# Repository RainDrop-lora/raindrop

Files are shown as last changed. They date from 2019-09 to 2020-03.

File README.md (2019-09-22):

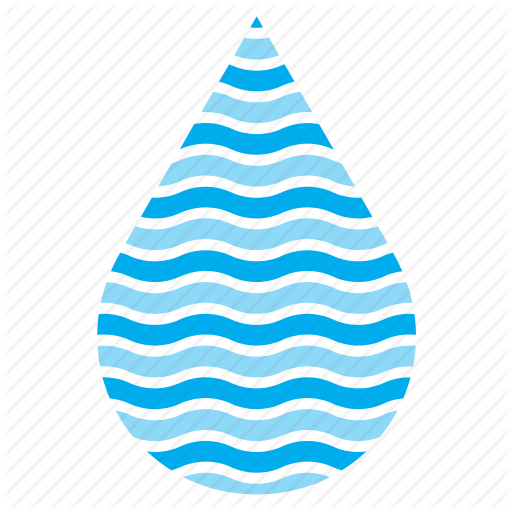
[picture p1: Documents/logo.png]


# RainDrop

Soil moisture monitoring system on LoRaWAN Network

## Problem

Resources watering city greenery are 
used sub-optimally.
It is complicated for the city to 
monitor work of subcontractors responsible
for city plants.
Rapidly changing climate makes watering an important task.

## Solution
System of wireless sensors that
measures soil moisture.

## Gains
* Municipality Gains means to evaluate work of subcontractors
* Community gains means to take care of community-planted trees
* Business gains means to optimally allocate resources 

## Architecture
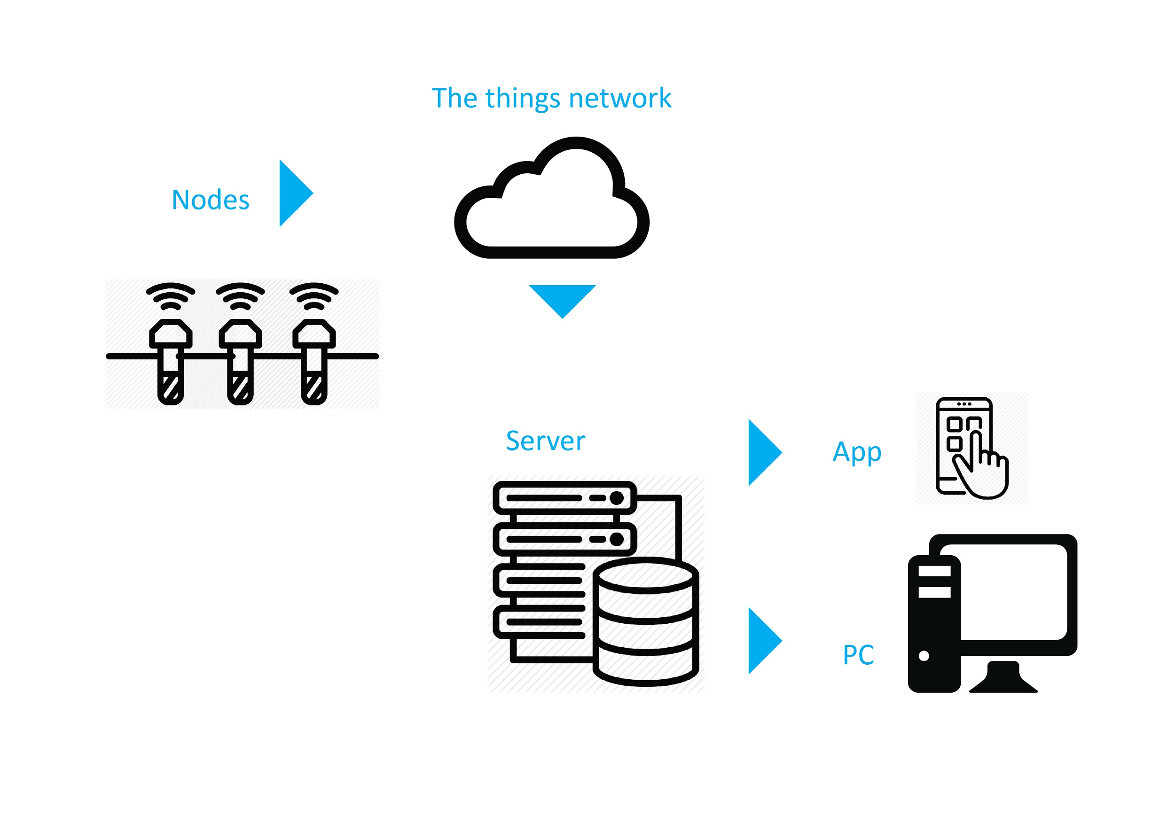
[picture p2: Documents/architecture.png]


## Results
* hardware prototype
* backend prototype
* cost analysis
* enduser application prototype
* all work is released under open source licence

## Plans
* order the first batch of PCBs next week
* work on battery life optimization
* deploy two LoRa gateways in next month

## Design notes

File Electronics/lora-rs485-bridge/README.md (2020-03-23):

# LoRa - RS485 bridge

This is a board that is specifically designed to easily hook up RS485 and I2C sensors to LoRaWAN network.
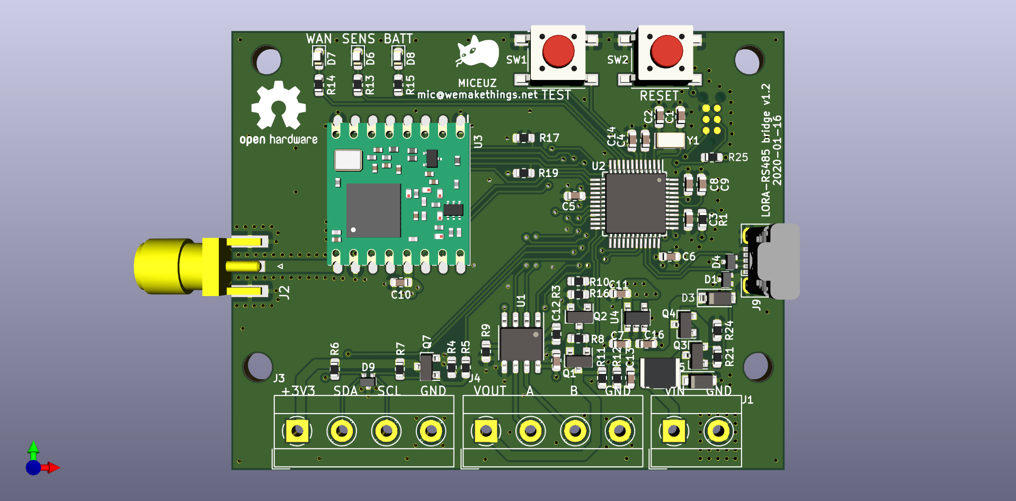
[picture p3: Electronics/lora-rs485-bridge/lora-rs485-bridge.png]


## Features

* Arduino compatible (Adafruit Feather M0 based)
* Low power:
  * Sleep current - 15uA
  * Message cost @ SF7 - 38mC (~190k messages from 4xAA battery)
  * Power switching for external I2C and RS485 sensors
* ESD protection
* Reverse polarity protection
* Wide input voltage range (up to 12V)
* Footprint for edge SMA antenna connector 

## Hardware resources

 * Connector J1 is power input, 12V max
 * Connector J4 is RS485 interface. VOUT on this connector is connected directly to the positive power input. Current of up to 500mA can be supplied from this connector. Q2 and Q1 form a high side switch to switch power to the connected RS485 bus. Digital pin **2** in Arduino environment can be used to switch power on and off.
 * Connector J3 is I2C interface. +3V3 on this connector is connected to the onboard +3V3 regulator. Up to 100mA can be supplied from this connector. R6 and R7 are I2C pullup resistors with the value of 4.7Ohm. Q7 is a switch that controls power to this connector. Digital pin **5** in Arduino environment can be used to controll this switch. Control logic is inverted, i.e. writing pin 5 HIGH will disconnect power to J3 and pullups, writing pin 5 LOW, will connect +3V3 to J3 and pullups.
 * SWD connector is provided for debugging and low level programming. 6-pin [Tag-Connect](https://www.tag-connect.com/product-category/products/cables/6-pin-target) connector can be used
 * Battery level is measured thru resistors R11, R12. Battery voltage is provided to this resistive divider when power to RS485 port is enabled. Voltage proportional to battery voltage is provided on analog pin **A0**. If using power supplies higher than 9V adjust values of resistors R11, R12 accordingly.
 * Led WAN is connected to digital pin **18**
 * Led SENS is connected to digital pin **17**
 * Led BATT is connected to digital pin **16**
 * Button TEST is connected to pin **A1**
 * Button RESET is connected to RESET line of the microcontroller U2.

## Power

The board is designed to be used with 4xAA 1.5V cells, actually physical dimensions of the board resemble a common cheap 4xAA holder. This strategy was chosen because for low power device it makes little sense to use recheargable batteries as you probably will not want to bring back device from field to charge it, it's much more practical to just change the batteries. 4xAA configuration allows to use up full capacity of AA cell - typically AA cells are totally flat at 0.8V, thus the circuit will stay fully operational till the batteries are flat - 0.8x4=3.2V while microcontroller works down to 2.5V and RFM69 module works down to 1.8V. 

Nevertheless, power sources up to 12V can be used. Also rechargeable LiPo cells can be used. 

## Antenna

A SMA connector is available on board, a right angle SMA connector designed for 1.6mm thickness board can be fitted. 

Nevertheless, a simple wire works just fine, I was able to transmit messages up to 10km away using a simple piece of wire as an antenna. Solder a piece of single core wire and cut it to a length for your frequency:
 * 868Mhz - 86.3mm
 * 915MHz - 81.9mm

## Firmware

A working example firmware source code is provided. The firmware takes care of setting up radio module, sleep, querying sensors and formatting payload and transmission. 

### Programming environment setup

A tutorial provided by [Adafruit for Feather M0 boards](https://learn.adafruit.com/adafruit-feather-m0-basic-proto/setup) can be followed for the programming environment setup. In a nutshell:

 * Use Arduino IDE version 1.8 or higher
 * Add this line to **Additional Boards Manager URLs** in preferences dialog: `https://adafruit.github.io/arduino-board-index/package_adafruit_index.json`
 * In the **Boards Manager** add support for **Arduino SAMD Boards** version 1.6.11 or later
 * In the **Boards Manager** add support for **Adafruit SAMD Boards**
 * In **Tools->Board** menu choose **Feather M0**; that's it, you are ready to go

### Libraries used

 * [arduino-lmic](https://github.com/mcci-catena/arduino-lmic) -- you can add it via Arduino Library manager, but cloning the git repo is strongly recommended to get all the latest fixes
 * [RTCZero](https://github.com/arduino-libraries/RTCZero) -- can be installed from Arduino Library manager

## Indication and UI

Three leds are provided on the board called WAN, SENS and BATT. It is up to the user to decide how exaclty to use them, but general guidance is that WAN led displays radio activity, SENS led provides sensor activity or status indication and BATT led provides battery status indication.

RESET and TEST buttons are available. RESET button resets the microcontroller, also it can be used to enter the bootloader mode for firmware upload. If sleep is utilised in the firmware, doubleclick the RESET button to enter the bootloader.

TEST button usage is up to the user.

Serial port is availale via USB-CDC interface, it can be used for debug messages, command line interface or other uses to be decided by the user. Note that in sleep mode USB is disconnected, disable sleep in the firmware to use the serial port.

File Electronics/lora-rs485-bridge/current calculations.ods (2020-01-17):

 | Typical, uA | Max, uA
TVS | 1 | 5
MCU | 4 | 12
Regulator | 4 | 8
RS485 | 4.1 | 6
Radio | 0.2 | 1
 | 13.3 | 32
 |  | uA
Reg+MCU in deep sleep |  | 7.8
Reg+MCU+Radio |  | 59

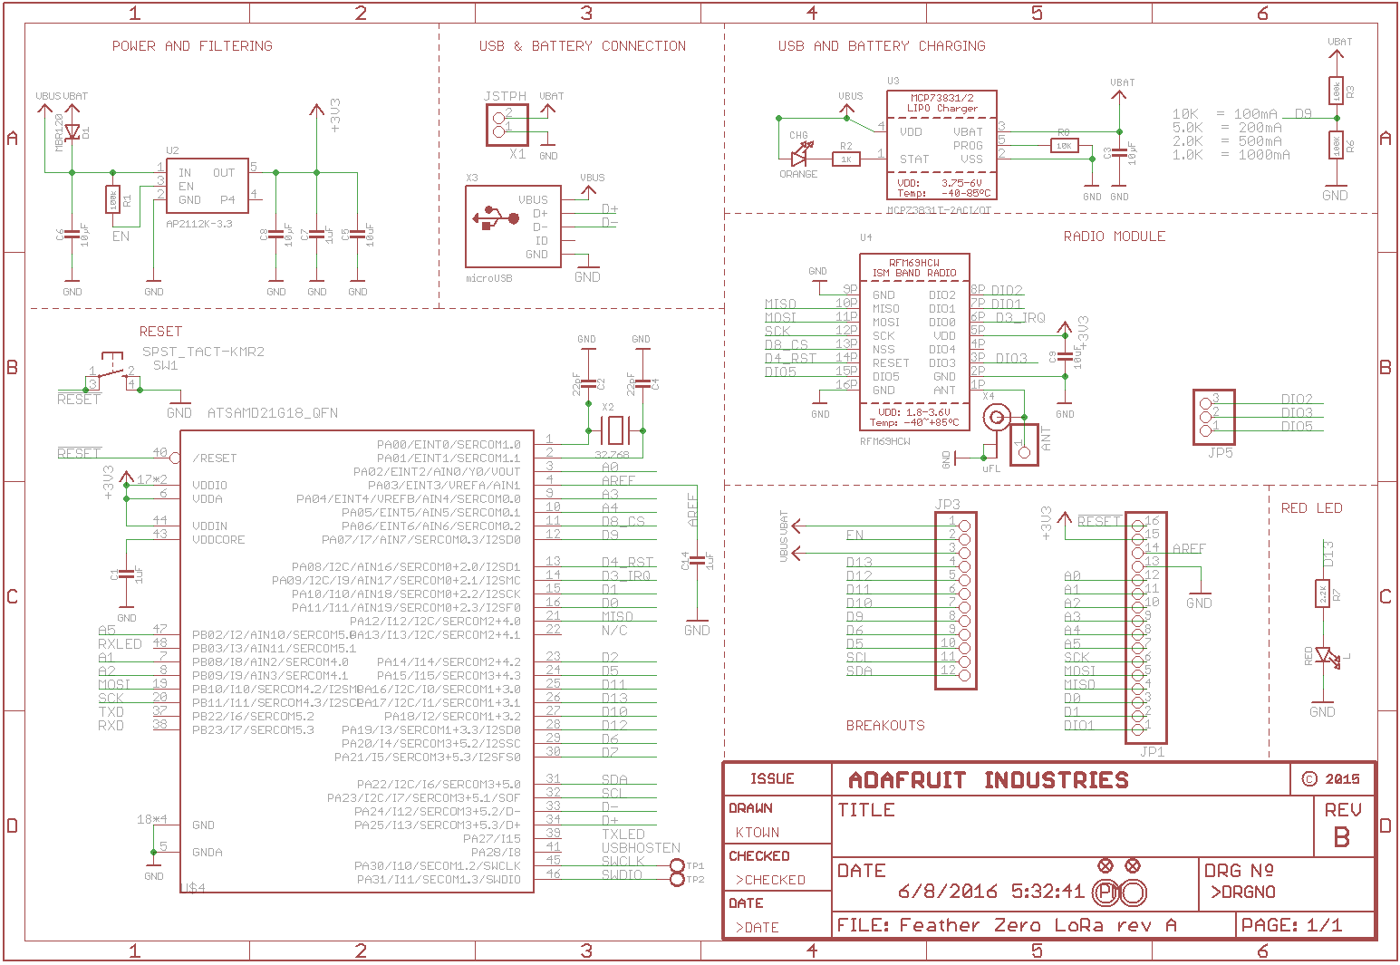
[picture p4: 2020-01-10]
Electronics/lora-rs485-bridge/feather_schem.png

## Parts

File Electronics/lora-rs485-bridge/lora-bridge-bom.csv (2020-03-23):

Item | Qty | Reference(s) | Value | Footprint | DNP | PartNo | Manufacturer | Comment
1 | 2 | C1, C2 | 22p | Capacitor_SMD:C_0603_1608Metric
2 | 9 | C3, C4, C5, C6, C8, C9, C12, C13, C14 | 1u | Capacitor_SMD:C_0603_1608Metric |  |  |  | Generic X5R capacitor
3 | 4 | C7, C10, C11, C16 | 4.7u | Capacitor_SMD:C_0603_1608Metric |  | C1608X5R1C475K080AE | TDK
4 | 3 | D1, D4, D9 | D_TVS_x2_AAC | miceuz-lib:SC89 |  | NZL5V6AXV3T1G | ON SEMICONDUCTOR
5 | 1 | D2 | 7.6V | Diode_SMD:D_SOD-323 |  | MM3Z7V5ST1G | ON SEMI
6 | 1 | D3 | 1N4148 | Diode_SMD:D_SOD-123 |  | 1N4148W-7-F | Diodes Inc
7 | 1 | D5 | D_TVS | Diode_SMD:D_SOD-123F |  | SMF11A | Littlefuse
8 | 3 | D6, D7, D8 | LED | LED_SMD:LED_0603_1608Metric
9 | 1 | J1 | battery | TerminalBlock_MetzConnect:TerminalBlock_MetzConnect_Type101_RT01602HBWC_Pitch5.08mm
10 | 1 | J2 | ANT | miceuz-lib:SMA_6.35_EdgeMount |  | CON-SMA-EDGE-S | RF Solutions | Can be replaced with compatible footprint connector specified up to 3GHz, VSWR < 1.2
11 | 1 | J3 | i2c | TerminalBlock_MetzConnect:TerminalBlock_MetzConnect_Type101_RT01604HBWC_Pitch5.08mm
12 | 1 | J4 | rs485 | TerminalBlock_MetzConnect:TerminalBlock_MetzConnect_Type101_RT01604HBWC_Pitch5.08mm
13 | 1 | J5 | SWD | miceuz-lib:TC2030-MCP-NL | DNP
14 | 1 | J9 | USB micro | Connectors_USB:USB_Micro-B_Vertical_Molex-105133-0001 |  | 1051330011 | MOLEX
15 | 4 | Q1, Q3, Q4, Q7 | Q_PMOS_GSD | Package_TO_SOT_SMD:SOT-23 |  | NX2301P,215 | NXP | Exact as specified
16 | 1 | Q2 | Q_NMOS_GSD | Package_TO_SOT_SMD:SOT-23 |  | NTR4003NT1G | ON SEMICONDUCTOR
17 | 5 | R1, R13, R14, R15, R25 | 1k | Resistor_SMD:R_0603_1608Metric
18 | 9 | R3, R4, R8, R9, R16, R17, R19, R21, R24 | 1M | Resistor_SMD:R_0603_1608Metric |  |  |  | Generic 5% resistor
19 | 2 | R5, R10 | 150 | Resistor_SMD:R_0603_1608Metric
20 | 2 | R6, R7 | 4.7k | Resistor_SMD:R_0603_1608Metric
21 | 1 | R11 | 20k | Resistor_SMD:R_0603_1608Metric
22 | 1 | R12 | 10k | Resistor_SMD:R_0603_1608Metric
23 | 1 | SW1 | SW_Test | Button_Switch_SMD:SW_Push_1P1T_NO_6x6mm_H9.5mm
24 | 1 | SW2 | SW_Reset | Button_Switch_SMD:SW_Push_1P1T_NO_6x6mm_H9.5mm
25 | 1 | TH1 | Thermistor_PTC | Fuse:Fuse_1206_3216Metric |  | nSMD075-13.2V | TECHFUSE
26 | 1 | U1 | SN65HVD72 | Package_SO:SOIC-8_3.9x4.9mm_P1.27mm |  | SN65HVD72DR | TEXAS INSTRUMENTS
27 | 1 | U2 | ATSAMD21G18A-AUT | Package_QFP:TQFP-48_7x7mm_P0.5mm |  | ATSAMD21G18A-AUT | Microchip
28 | 1 | U3 | RFM95W-868S2 | miceuz-lib:RFM95 |  | RFM95W-868S2 | HopeRF
29 | 1 | U4 | NCP718 | TO_SOT_Packages_SMD:SOT-23-5 |  | NCP718ASN330T1G | ON SEMICONDUCTOR
30 | 1 | Y1 | 32.768 | Crystals:Crystal_SMD_3215-2pin_3.2x1.5mm |  | FC-135 32.7680KA-A5 | EPSON

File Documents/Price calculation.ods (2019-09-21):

Name | Price, Eur
Electronic parts | 15 | 15 | 15 | 38.4
Electronic assembly | 3.5 | 3.5 | 3.5
Antenna | 1.8 | 1.8 | 1.8
Battery holder | 0.6 | 0.6 | 0.6
Case | 8.45 | 8.45 | 8.45
Cable gland | 0.2 | 0.2 | 0.2
Fixing parts | 5
Welding | 5
Belt | 5.2
Screws, etc | 1 | 1 | 1
Assembly | 2 | 2 | 2
Sensor | 16.34 | 16 | 0
Total | 64.09 | 48.55 | 32.55
+60% markup | 38.454 | 29.13 | 19.53
Sale price | 102.544 | 77.68 | 52.08
 |  |  | 83.328

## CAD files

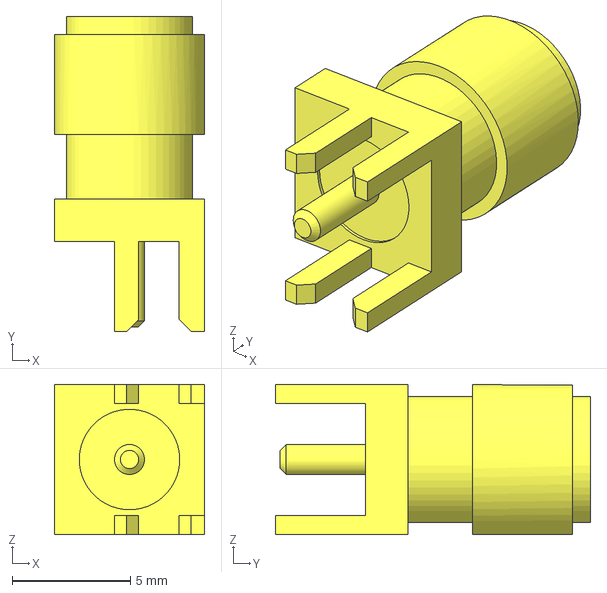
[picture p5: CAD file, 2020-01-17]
Electronics/lora-rs485-bridge/SMA-J-P-H-ST-EM1.STP--3DModel-STEP-66336.STEP
6.35 x 13.3 x 6.35 mm

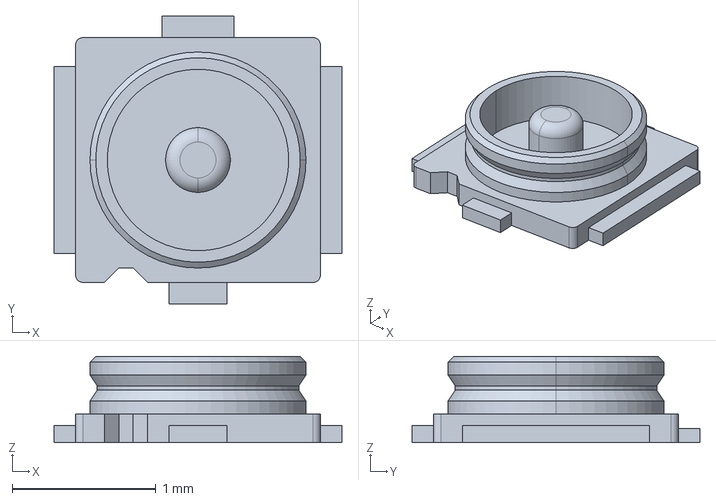
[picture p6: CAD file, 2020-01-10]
Electronics/lora-rs485-bridge/c-2334884-1-a2-3d.stp
2.00 x 2.00 x 0.6 mm

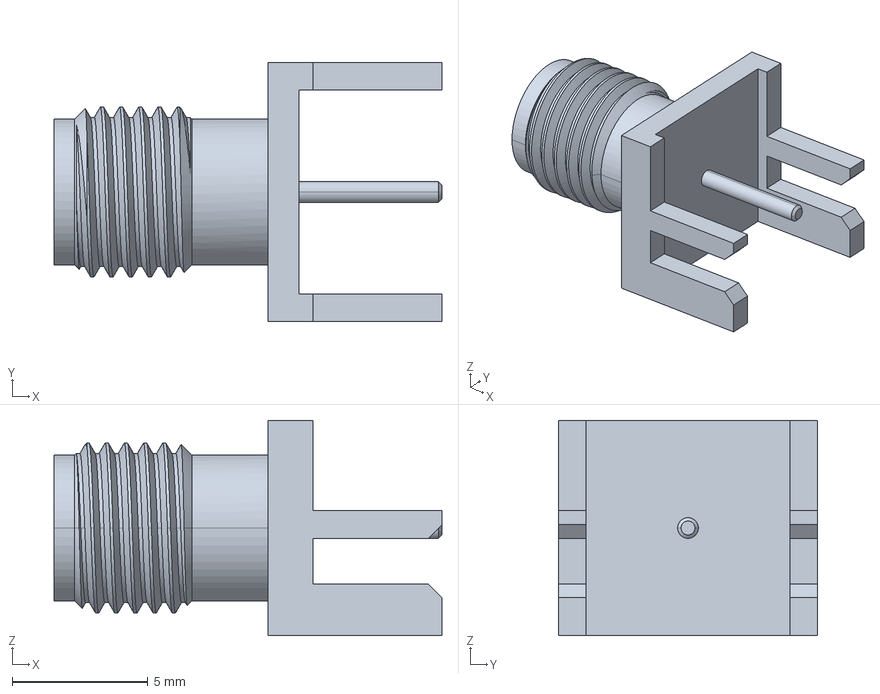
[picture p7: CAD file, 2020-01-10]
Electronics/lora-rs485-bridge/732511150.stp
14.3 x 9.53 x 7.92 mm

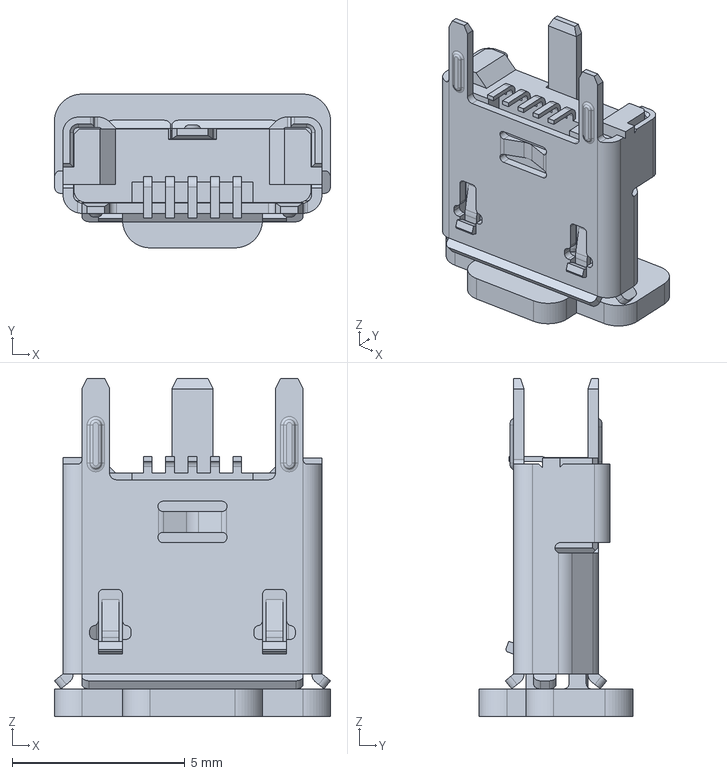
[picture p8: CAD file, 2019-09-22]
Electronics/lora-rs485-bridge/1051330011.stp
8.00 x 4.45 x 9.78 mm

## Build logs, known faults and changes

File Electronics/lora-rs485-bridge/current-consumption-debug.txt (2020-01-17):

# V1.0 board is analysed

Both MCU and RFM95 are in sleep.

VCC - 6V

Overall current consumption stays at 305uA

* RFM95 VCC pin draws 0.5uA 
* RFM95 GND current is 0.5uA

RFM95 removed from board, RS485 transceiver removed
Board cleaned

pin level is set to default sleep value before setting it as input -- this seems to have impact

Overall current consumption is 9uA

RS485 transceiver put back

Overall current consumption is 12uA

Code changed to enable RS485 transceiver at the startup

RFM95 soldered back with resistors:
 * DIO01 - 10k
 * IRQ - 10k
 * MISO - 10k
 * MOSI - 330
 * SCK - 330
 * NSS - 330
 * RST - 10k

RFM95 is not initialized in FW

Overall current consumption is 2mA

RFM95 initialization put back to FW

Overall current consumption is 10mA, MCU does not finish initializing RFM95

MISO resistor replaced to 220

Initialization passes. Current consumption is about 38uA
Touching MISO line at RFM95 size reduces current consumption down to 12uA
Rising the board from antistatic pad also reduces current consumption down to 10-12uA. 
Holding hand over board increases current consumption.

MISO resistor replaced with a link

Overall current consumption is 10uA
Board is on longer susceptable to hand movement or placement on antistatic pad

RST resistor replaced with a link

NO change - Overall current consumption is 10uA

DIO01 resistor replaced with a link

NO change - Overall current consumption is 10uA

IRQ resistor replaced with a link

NO change - Overall current consumption is 10uA

MOSI resistor replaced with a link

NO change - Overall current consumption is 10uA

SCK resistor replaced with a link

NO change - Overall current consumption is 10uA

NSS resistor replaced with a link

NO change - Overall current consumption is 10uA

* Conclusions: V1.0 board stays in 10uA sleep current with RFM95 connected with no resistors

# V1.1 board is analysed

VCC = 6V
all RFM95 pins are connected via 1k resistor

Overall sleep current is 60uA

Board cleaned with Isopropyl alcohol

Overall sleep current increased to over 100uA, a lot of 50Hz noise visible on current signal

Board cleaned with Isopropyl alcohol even more, MISO resistor replaced with 0 Ohm link

Overall sleep current dropped to 65uA

MOSI and SCK resistors replaced with 0 Ohm - no improvement

RFM95 removed - on improvement, current stays at ~74uA

R24 desoldered - current dropped to 9uA; D3 is a leaky Schottky!!!

D3 replaced with 1n4148 - current is 15uA which is nominal.

RFM95 soldered back

Overall sleep current is 15uA!!!

ALL resistors removed from RFM95 lines, sleep current is still 15uA

#FW changes

pins left as outputs with default sleep high/low states

Overall sleep current is 15uA

Add a 1M pulldown to MISO line - a slight improvement in current consumption - down to 14.5uA, no sensitivity to touching anymore.

# Active mode current consumption

* SF7 -  38mC per message
* SF8 -  43mC
* SF9 -  58mC
* SF10 - 68mC
* SF11 - 119mC
* SF12 - 182mC

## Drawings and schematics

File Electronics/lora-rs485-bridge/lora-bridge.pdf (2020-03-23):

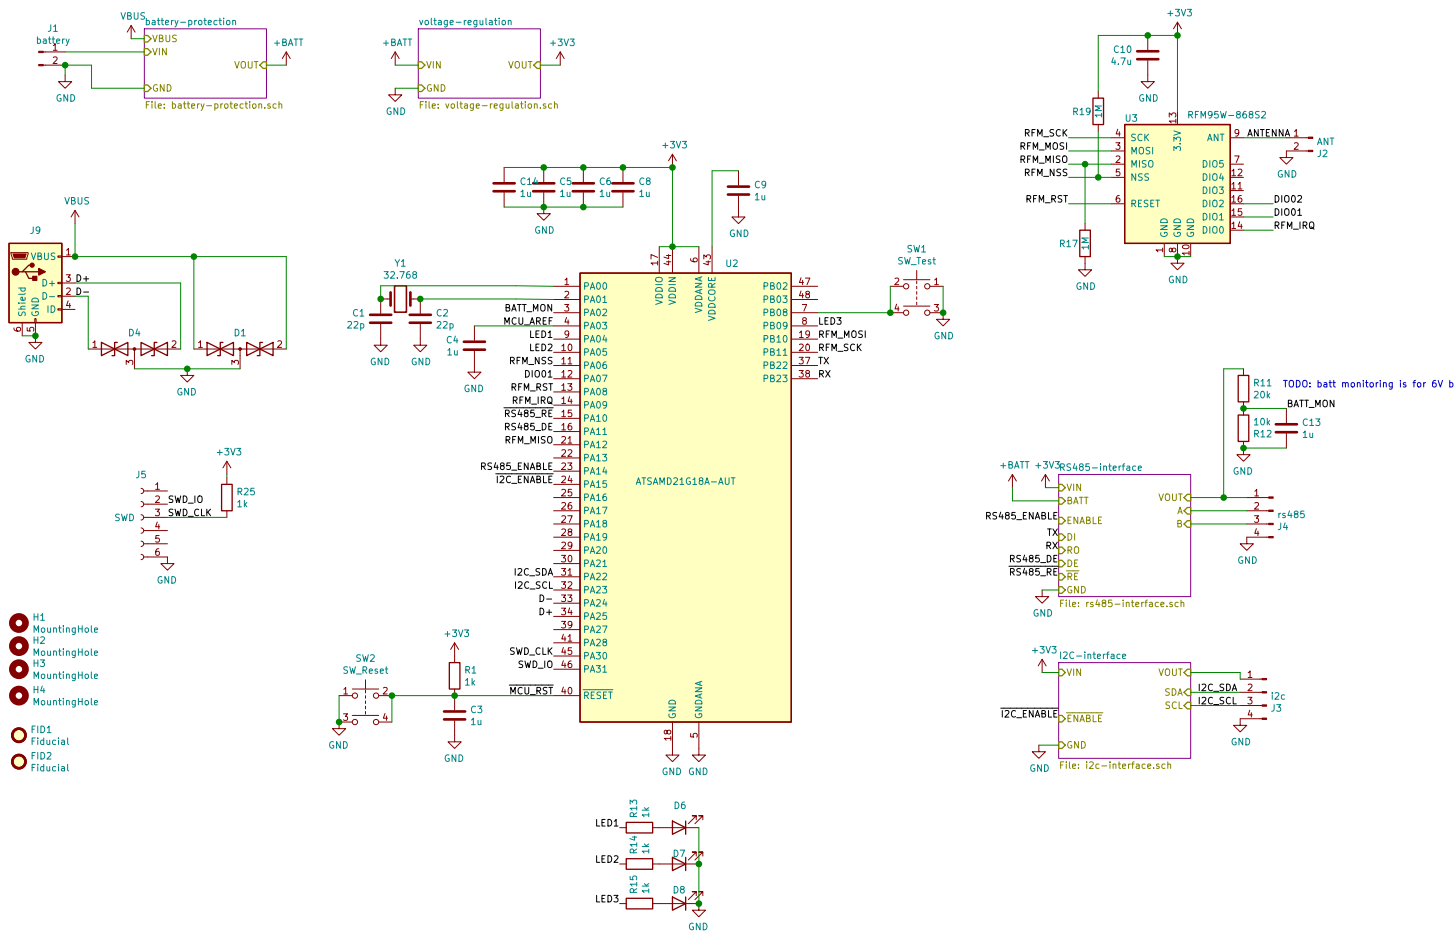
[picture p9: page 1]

battery-protection
VOUT VBUS GND
File: battery-protection.sch VIN

File: voltage-regulation.sch VIN GND

1 GND 10 DIO3 11 DIO4 12 3.3V 13 DIO0 14 DIO1 15 DIO2 16 MISO 2 MOSI 3 SCK 4 NSS 5 RESET 6 DIO5 7 GND

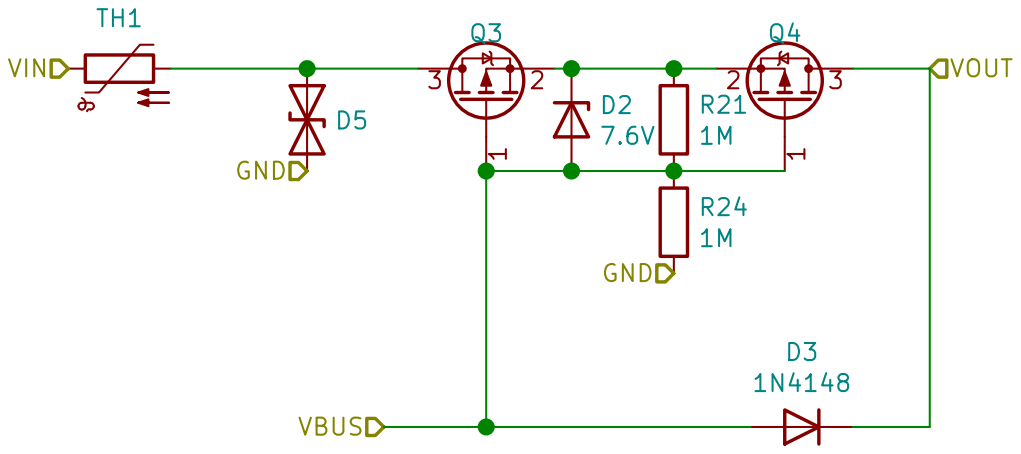
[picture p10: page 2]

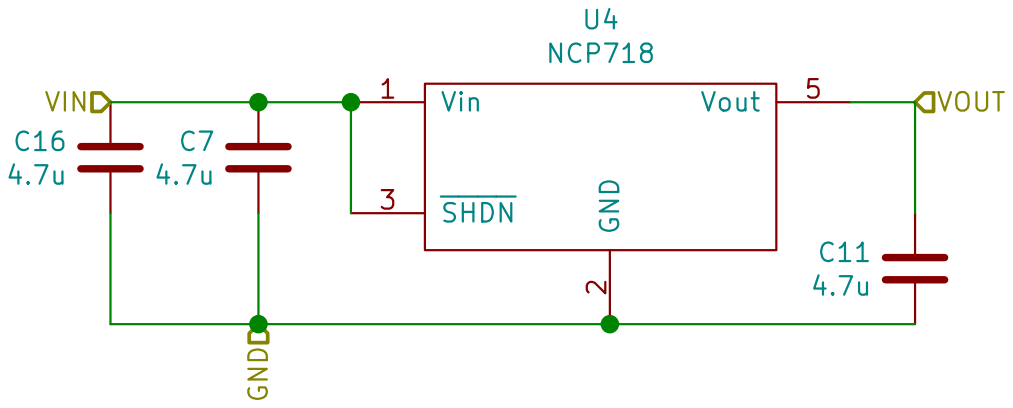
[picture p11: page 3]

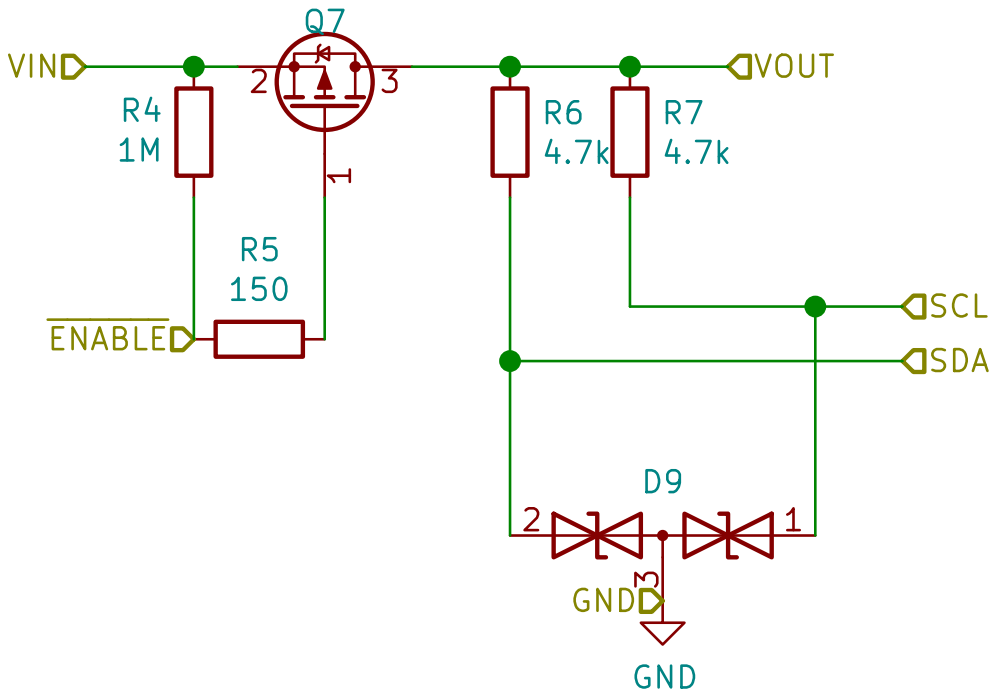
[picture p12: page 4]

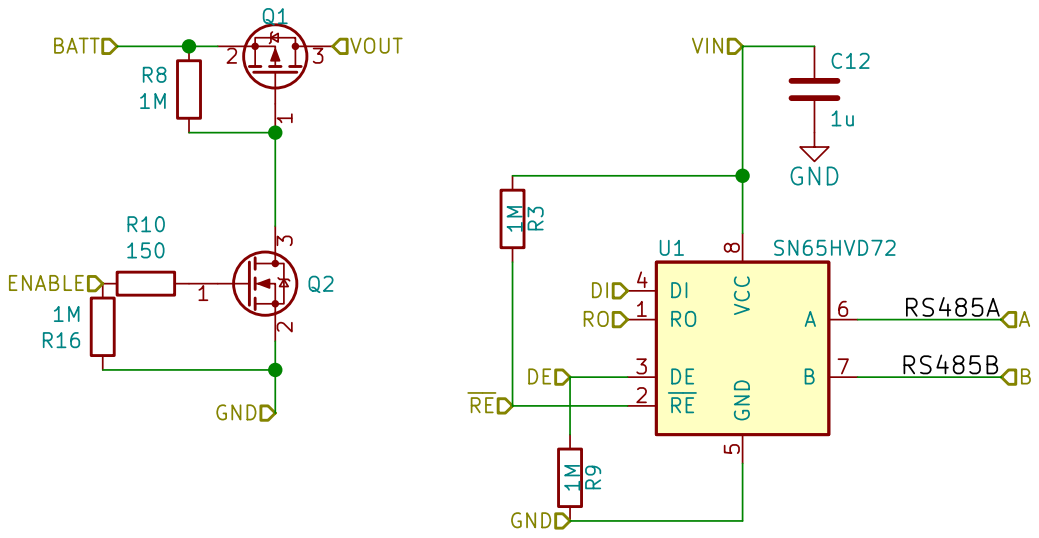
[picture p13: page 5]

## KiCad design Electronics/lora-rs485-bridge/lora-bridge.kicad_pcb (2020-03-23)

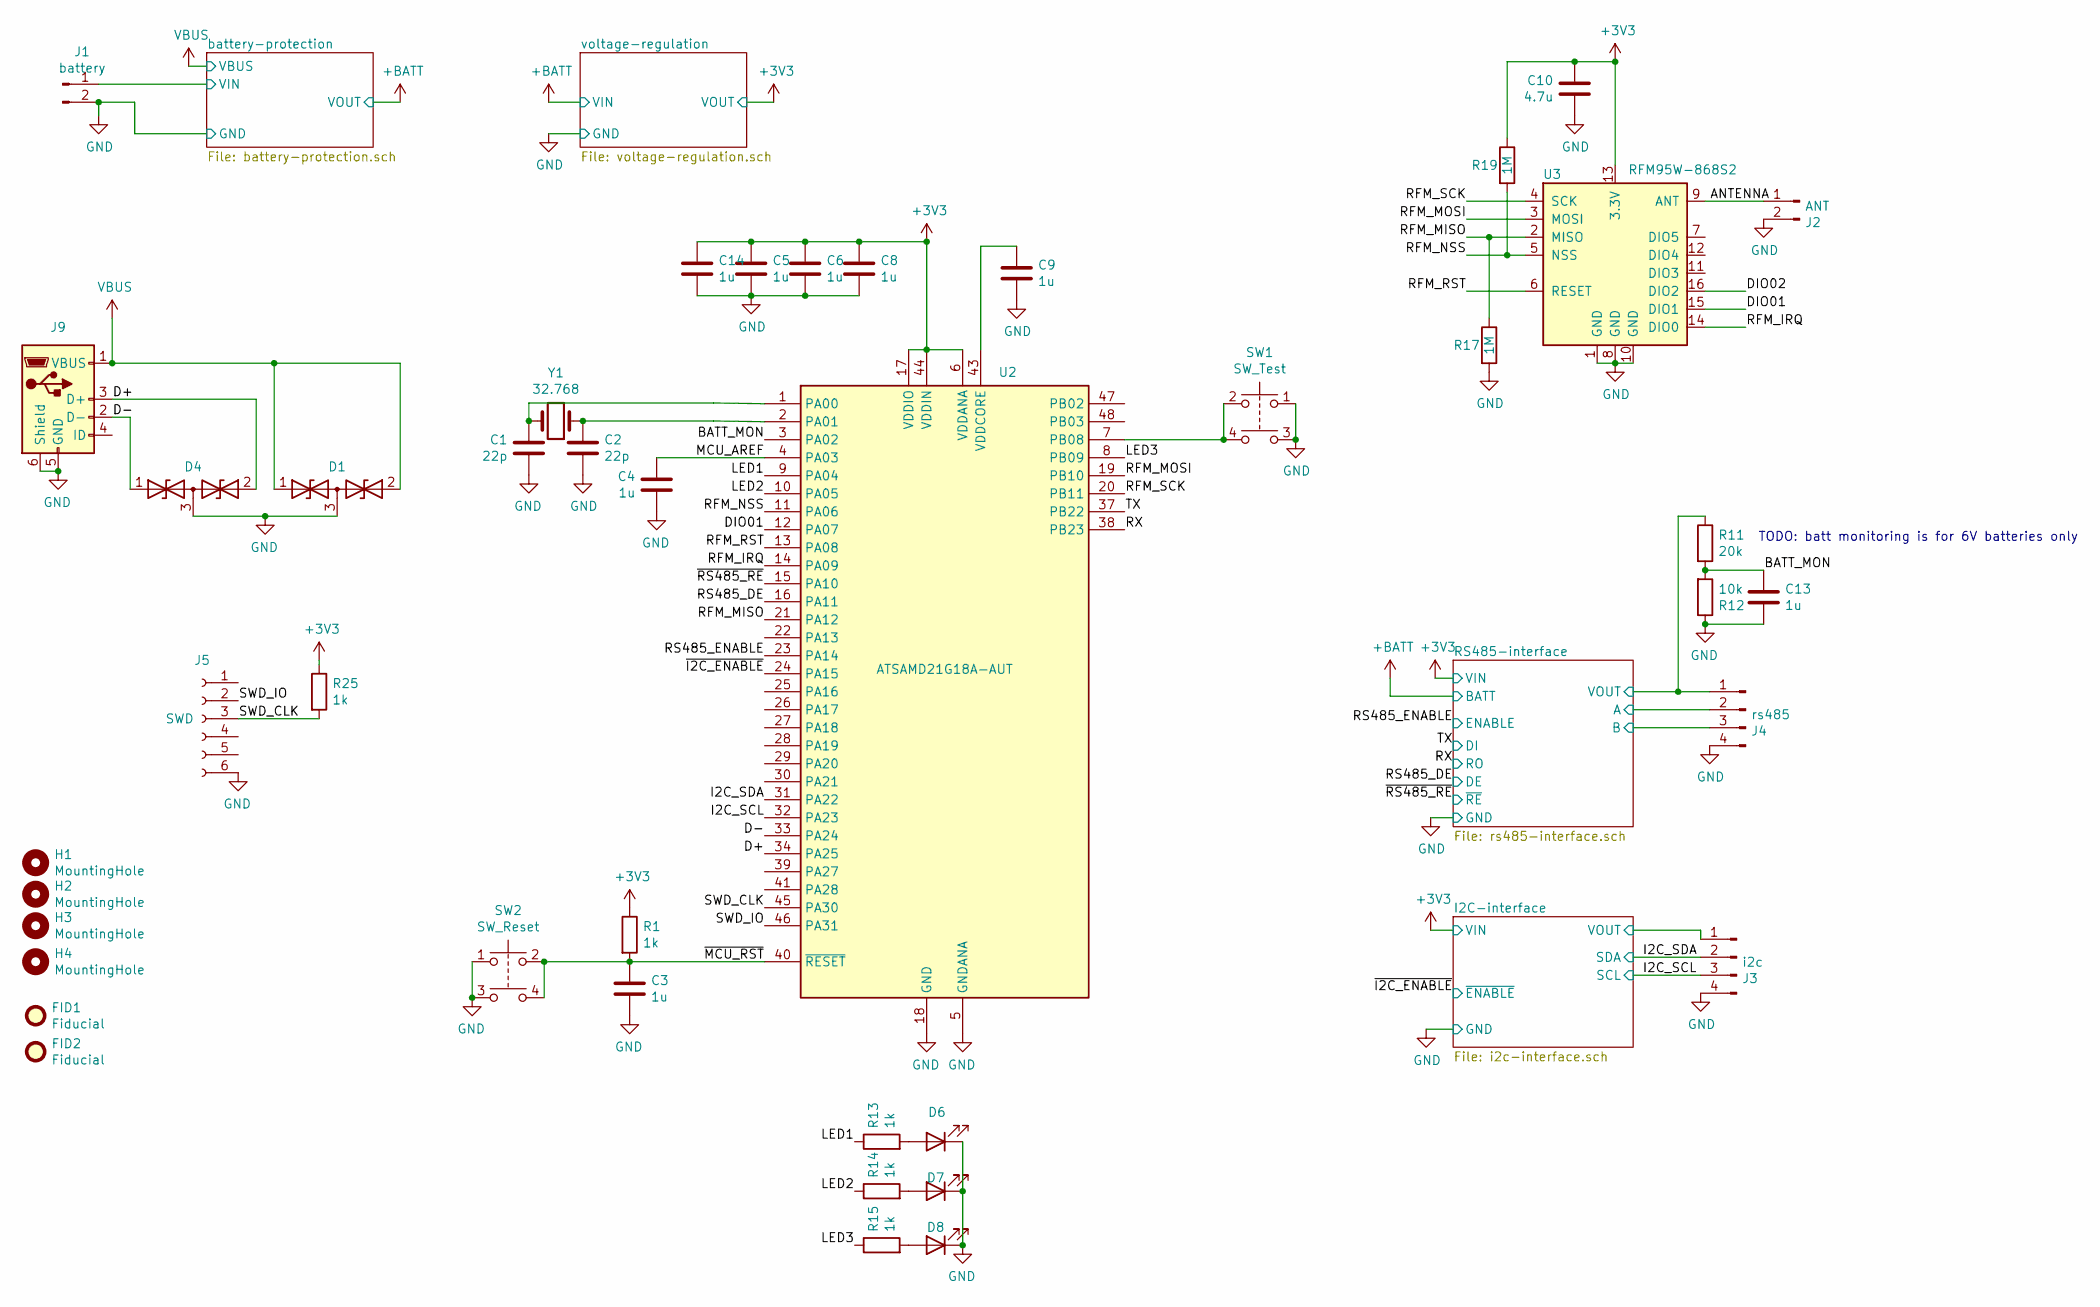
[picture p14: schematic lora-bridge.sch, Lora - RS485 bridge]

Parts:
C1, C2: 22p; C_0603_1608Metric
C3, C4, C5, C6, C8, C9, C13, C14: 1u; C_0603_1608Metric
C10: 4.7u; C_0603_1608Metric; PartNo C1608X5R1C475K080AE
D1, D4: D_TVS_x2_AAC; SC89; PartNo NZL5V6AXV3T1G
D6, D7, D8: LED; LED_0603_1608Metric
FID1, FID2: Fiducial; Fiducial_1mm_Dia_2mm_Outer
H1, H2, H3, H4: MountingHole; MountingHole_3.2mm_M3_DIN965
J1: battery; TerminalBlock_MetzConnect_Type101_RT01602HBWC_Pitch5.08mm
J2: ANT; SMA_6.35_EdgeMount; PartNo CON-SMA-EDGE-S
J3: i2c; TerminalBlock_MetzConnect_Type101_RT01604HBWC_Pitch5.08mm
J4: rs485; TerminalBlock_MetzConnect_Type101_RT01604HBWC_Pitch5.08mm
J5: SWD; TC2030-MCP-NL
J9: USB micro; USB_Micro-B_Vertical_Molex-105133-0001; PartNo 1051330011
R1, R13, R14, R15, R25: 1k; R_0603_1608Metric
R11: 20k; R_0603_1608Metric
R12: 10k; R_0603_1608Metric
R17, R19: 1M; R_0603_1608Metric
SW1: SW_Test; SW_Push_1P1T_NO_6x6mm_H9.5mm
SW2: SW_Reset; SW_Push_1P1T_NO_6x6mm_H9.5mm
U2: ATSAMD21G18A-AUT; TQFP-48_7x7mm_P0.5mm; PartNo ATSAMD21G18A-AUT
U3: RFM95W-868S2; RFM95; PartNo RFM95W-868S2
Y1: 32.768; Crystal_SMD_3215-2pin_3.2x1.5mm; PartNo FC-135 32.7680KA-A5

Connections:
+3V3: C5.1, C6.1, C8.1, C10.1, C14.1, R1.1, R19.1, R25.1, U2.6 (VDDANA), U2.17 (VDDIO), U2.36 (VDDIO), U2.44 (VDDIN), U3.13 (3.3V); also elsewhere on the board
/A: J4.2; also elsewhere on the board
/ANTENNA: J2.1, U3.9 (ANT)
/B: J4.3; also elsewhere on the board
/BATT_MON: C13.1, R11.2, R12.2, U2.3 (PA02)
/D+: D4.2 (A2), J9.3 (D+), U2.34 (PA25)
/D-: D4.1 (A1), J9.2 (D-), U2.33 (PA24)
/DIO01: U2.12 (PA07), U3.15 (DIO1)
/DIO02: U3.16 (DIO2)
/I2C_SCL: J3.3, U2.32 (PA23); also elsewhere on the board
/I2C_SDA: J3.2, U2.31 (PA22); also elsewhere on the board
/LED1: R13.1, U2.9 (PA04)
/LED2: R14.1, U2.10 (PA05)
/LED3: R15.1, U2.8 (PB09)
/MCU_AREF: C4.1, U2.4 (PA03)
/RFM_IRQ: U2.14 (PA09), U3.14 (DIO0)
/RFM_MISO: R17.1, U2.21 (PA12), U3.2 (MISO)
/RFM_MOSI: U2.19 (PB10), U3.3 (MOSI)
/RFM_NSS: R19.2, U2.11 (PA06), U3.5 (NSS)
/RFM_RST: U2.13 (PA08), U3.6 (RESET)
/RFM_SCK: U2.20 (PB11), U3.4 (SCK)
/RS485_DE: U2.16 (PA11); also elsewhere on the board
/RS485_ENABLE: U2.23 (PA14); also elsewhere on the board
/RX: U2.38 (PB23); also elsewhere on the board
/SWD_CLK: J5.3, R25.2, U2.45 (PA30)
/SWD_IO: J5.2, U2.46 (PA31)
/TX: U2.37 (PB22); also elsewhere on the board
/VIN: J1.1; also elsewhere on the board
/VOUT: J4.1, R11.1; also elsewhere on the board
/VOUT_1: J3.1; also elsewhere on the board
/~I2C_ENABLE: U2.24 (PA15); also elsewhere on the board
/~MCU_RST: C3.1, R1.2, SW2.2, SW2.4, U2.40 (~RESET)
/~RS485_RE: U2.15 (PA10); also elsewhere on the board
GND: C1.2, C2.2, C3.2, C4.2, C5.2, C6.2, C8.2, C9.2, C10.2, C13.2, C14.2, D1.3 (common), D4.3 (common), D6.1 (K), D7.1 (K), D8.1 (K), J1.2, J2.2, J3.4, J4.4, J5.6, J9.5 (GND), J9.6 (Shield), R12.1, R17.2, SW1.1, SW1.3, SW2.1, SW2.3, U2.5 (GNDANA), U2.18 (GND), U2.35 (GND), U2.42 (GND), U3.1 (GND), U3.8 (GND), U3.10 (GND); also elsewhere on the board
unnamed: C1.1, U2.1 (PA00), Y1.2
unnamed: C2.1, U2.2 (PA01), Y1.1
unnamed: C9.1, U2.43 (VDDCORE)
unnamed: D6.2 (A), R13.2
unnamed: D7.2 (A), R14.2
unnamed: D8.2 (A), R15.2
unnamed: SW1.2, SW1.4, U2.7 (PB08)
VBUS: D1.1 (A1), D1.2 (A2), J9.1 (VBUS); also elsewhere on the board

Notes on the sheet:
TODO: batt monitoring is for 6V batteries only

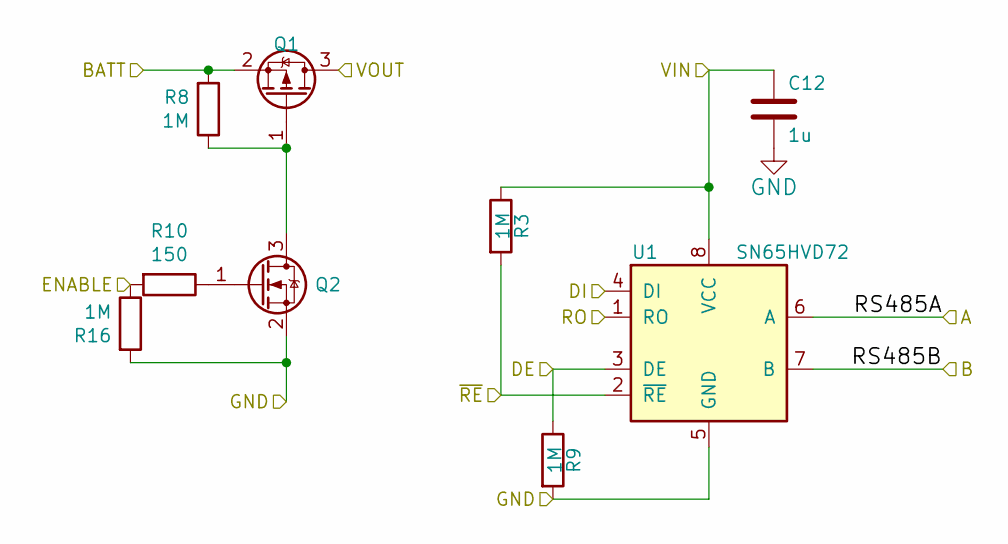
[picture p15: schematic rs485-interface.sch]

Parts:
C12: 1u; C_0603_1608Metric
Q1: Q_PMOS_GSD; SOT-23; PartNo NX2301P,215
Q2: Q_NMOS_GSD; SOT-23; PartNo NTR4003NT1G
R3, R8, R9, R16: 1M; R_0603_1608Metric
R10: 150; R_0603_1608Metric
U1: SN65HVD72; SOIC-8_3.9x4.9mm_P1.27mm; PartNo SN65HVD72DR

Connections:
+3V3: C12.1, R3.1, U1.8 (VCC); also elsewhere on the board
+BATT: Q1.2 (S), R8.2; also elsewhere on the board
/A: U1.6 (A); also elsewhere on the board
/B: U1.7 (B); also elsewhere on the board
/RS485_DE: R9.1, U1.3 (DE); also elsewhere on the board
/RS485_ENABLE: R10.2, R16.1; also elsewhere on the board
/RX: U1.1 (RO); also elsewhere on the board
/TX: U1.4 (DI); also elsewhere on the board
/VOUT: Q1.3 (D); also elsewhere on the board
/~RS485_RE: R3.2, U1.2 (~RE~); also elsewhere on the board
GND: C12.2, Q2.2 (S), R9.2, R16.2, U1.5 (GND); also elsewhere on the board
unnamed: Q1.1 (G), Q2.3 (D), R8.1
unnamed: Q2.1 (G), R10.1

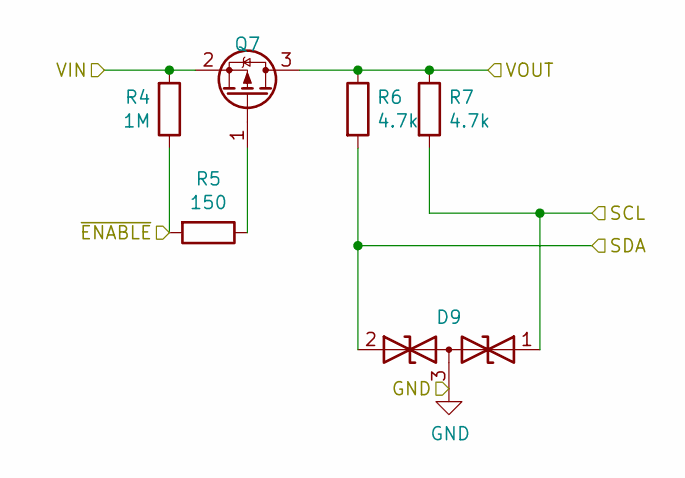
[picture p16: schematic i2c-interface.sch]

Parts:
D9: D_TVS_x2_AAC; SC89; PartNo NZL5V6AXV3T1G
Q7: Q_PMOS_GSD; SOT-23; PartNo NX2301P,215
R4: 1M; R_0603_1608Metric
R5: 150; R_0603_1608Metric
R6, R7: 4.7k; R_0603_1608Metric

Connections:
+3V3: Q7.2 (S), R4.2; also elsewhere on the board
/I2C_SCL: D9.1 (A1), R7.2; also elsewhere on the board
/I2C_SDA: D9.2 (A2), R6.2; also elsewhere on the board
/VOUT_1: Q7.3 (D), R6.1, R7.1; also elsewhere on the board
/~I2C_ENABLE: R4.1, R5.2; also elsewhere on the board
GND: D9.3 (common); also elsewhere on the board
unnamed: Q7.1 (G), R5.1

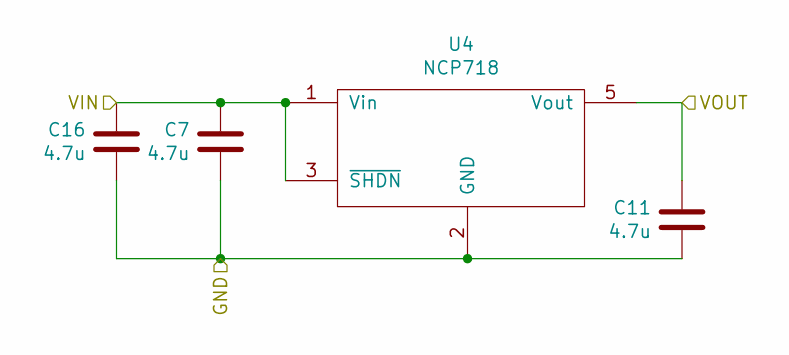
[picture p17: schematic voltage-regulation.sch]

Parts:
C7, C11, C16: 4.7u; C_0603_1608Metric; PartNo C1608X5R1C475K080AE
U4: NCP718; SOT-23-5; PartNo NCP718ASN330T1G

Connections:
+3V3: C11.1, U4.5 (Vout); also elsewhere on the board
+BATT: C7.1, C16.1, U4.1 (Vin), U4.3 (~SHDN); also elsewhere on the board
GND: C7.2, C11.2, C16.2, U4.2 (GND); also elsewhere on the board

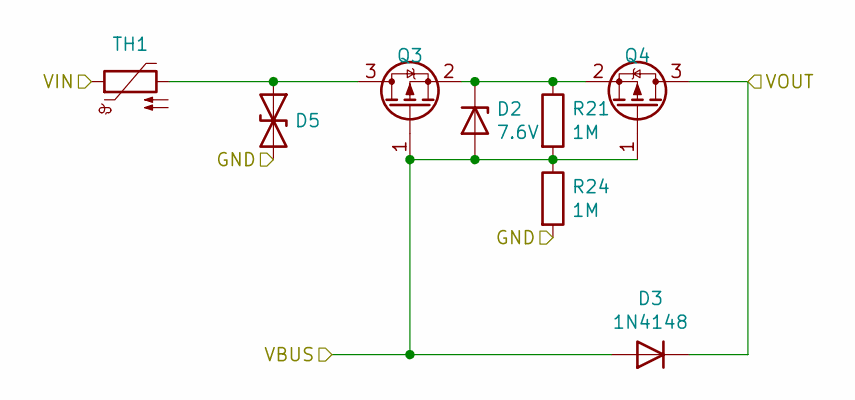
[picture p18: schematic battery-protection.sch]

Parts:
D2: 7.6V; D_SOD-323; PartNo MM3Z7V5ST1G
D3: 1N4148; D_SOD-123; PartNo 1N4148W-7-F
D5: D_TVS; D_SOD-123F; PartNo SMF11A
Q3, Q4: Q_PMOS_GSD; SOT-23; PartNo NX2301P,215
R21, R24: 1M; R_0603_1608Metric
TH1: Thermistor_PTC; Fuse_1206_3216Metric; PartNo nSMD075-13.2V

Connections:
+BATT: D3.1 (K), Q4.3 (D); also elsewhere on the board
/VIN: TH1.1; also elsewhere on the board
GND: D5.2 (A2), R24.2; also elsewhere on the board
unnamed: D2.1 (K), Q3.2 (S), Q4.2 (S), R21.1
unnamed: D5.1 (A1), Q3.3 (D), TH1.2
VBUS: D2.2 (A), D3.2 (A), Q3.1 (G), Q4.1 (G), R21.2, R24.1; also elsewhere on the board

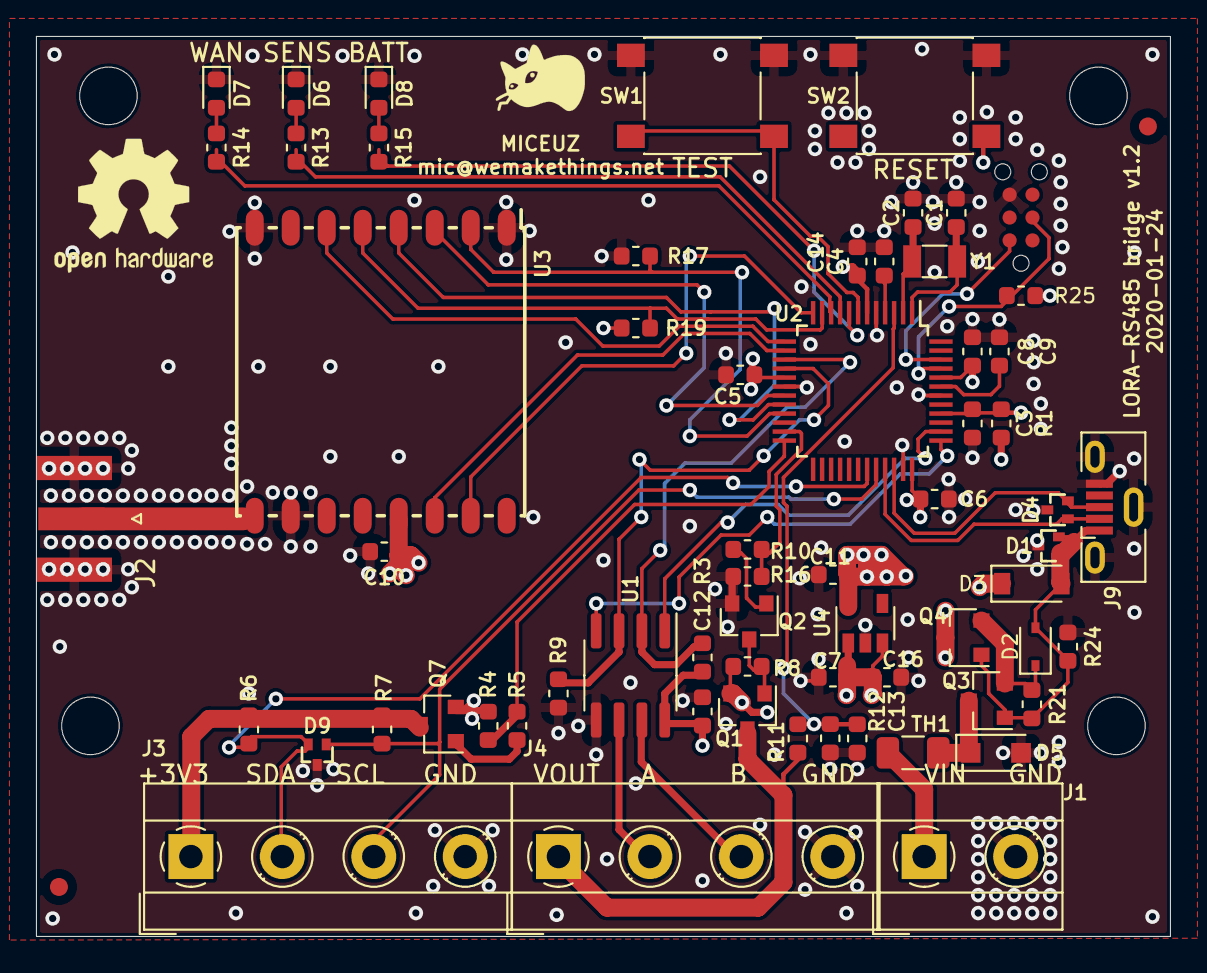
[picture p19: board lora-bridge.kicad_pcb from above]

Board: 4 copper layers, 63.0 x 50.0 mm, 69 parts (0 on the bottom side), 47 nets.

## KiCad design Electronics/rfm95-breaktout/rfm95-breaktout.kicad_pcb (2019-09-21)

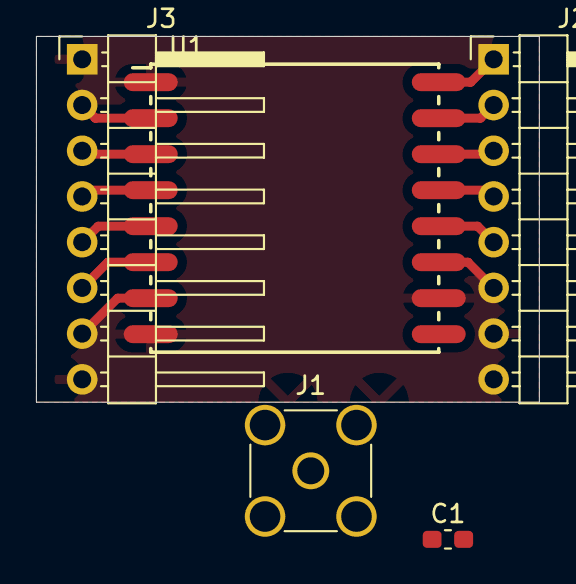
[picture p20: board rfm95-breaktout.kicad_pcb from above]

Board: 2 copper layers, 27.9 x 20.3 mm, 5 parts (0 on the bottom side), 14 nets.

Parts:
C1: C; C_0603_1608Metric_Pad1.05x0.95mm_HandSolder
J1: ANT; SMA_Amphenol_901-144_Vertical
J2, J3: Conn_01x08; Pin_Header_Angled_1x08_Pitch2.54mm
U1: RFM95W-868S2; RFM95

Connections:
+3V3: C1.1, J2.4, U1.13
/ANT: J1.1, U1.9
/DIO01: J2.2, U1.15
/DIO02: J2.1, U1.16
/DIO03: J2.6, U1.11
/DIO04: J2.5, U1.12
/DIO5: J3.7, U1.7
/RFM_IRQ: J2.3, U1.14
/RFM_MISO: J3.2, U1.2
/RFM_MOSI: J3.3, U1.3
/RFM_NSS: J3.5, U1.5
/RFM_RST: J3.6, U1.6
/RFM_SCK: J3.4, U1.4
GND: C1.2, J1.2, J2.7, J3.1, J3.8, U1.1, U1.8, U1.10

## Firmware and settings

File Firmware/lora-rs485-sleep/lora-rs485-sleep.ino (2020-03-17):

/*******************************************************************************
 * The Things Network - Sensor Data Example
 * 
 * Example of sending a valid LoRaWAN packet with DHT22 temperature and
 * humidity data to The Things Networ using a Feather M0 LoRa.
 * 
 * Learn Guide: https://learn.adafruit.com/the-things-network-for-feather
 * 
 * Copyright (c) 2015 Thomas Telkamp and Matthijs Kooijman
 * Copyright (c) 2018 Terry Moore, MCCI
 * Copyright (c) 2018 Brent Rubell, Adafruit Industries
 * 
 * Permission is hereby granted, free of charge, to anyone
 * obtaining a copy of this document and accompanying files,
 * to do whatever they want with them without any restriction,
 * including, but not limited to, copying, modification and redistribution.
 * NO WARRANTY OF ANY KIND IS PROVIDED.
 *******************************************************************************/
#define CRYSTALLESS 1

#include <lmic.h>
#include <hal/hal.h>
#include <SPI.h>
#include <ModbusMaster.h>
#include <RTCZero.h>

ModbusMaster sensor;


#define DE 0
#define RE 1

#define LED_WAN 18
#define LED_SENSOR 17
#define LED_BATT 16
#define RS_485_EN 2
#define I2C_EN 5


RTCZero rtc;

void alarmMatch() {
}

void preTransmission() {
  digitalWrite(RE, HIGH);
  digitalWrite(DE, HIGH);
}

void postTransmission() {
  digitalWrite(DE, LOW);
  digitalWrite(RE, LOW);
}

// This EUI must be in little-endian format, so least-significant-byte
// first. When copying an EUI from ttnctl output, this means to reverse
// the bytes. For TTN issued EUIs the last bytes should be 0xD5, 0xB3,
// 0x70.
static const u1_t PROGMEM APPEUI[8] = { 0x67, 0x29, 0x02, 0xD0, 0x7E, 0xD5, 0xB3, 0x70 };
void os_getArtEui (u1_t* buf) { memcpy_P(buf, APPEUI, 8);}

// This should also be in little endian format, see above.
static const u1_t PROGMEM DEVEUI[8] = { 0x92, 0x6A, 0xA0, 0xC2, 0xAF, 0x2D, 0x7D, 0x00 };
void os_getDevEui (u1_t* buf) { memcpy_P(buf, DEVEUI, 8);}

// This key should be in big endian format (or, since it is not really a
// number but a block of memory, endianness does not really apply). In
// practice, a key taken from the TTN console can be copied as-is.
static const u1_t PROGMEM APPKEY[16] = { 0x22, 0xB0, 0x7C, 0x46, 0x58, 0xD3, 0x55, 0xD9, 0x4C, 0x57, 0x5C, 0xB0, 0x29, 0x26, 0x87, 0x4E };
void os_getDevKey (u1_t* buf) {  memcpy_P(buf, APPKEY, 16);}

// payload to send to TTN gateway
static uint8_t payload[5];
static osjob_t sendjob;





// Schedule TX every this many seconds (might become longer due to duty
// cycle limitations).
const unsigned TX_INTERVAL = 10;



const lmic_pinmap lmic_pins = {
  .nss = 8,                // Internal connected
  .rxtx = LMIC_UNUSED_PIN,
  .rst = 4,                // Internal connected
  .dio = {3, 9, LMIC_UNUSED_PIN},    // Connect "i01" to "5"
                    // Connect "D2" to "6"
  .rxtx_rx_active = 0,
  .rssi_cal = 8,              // LBT cal for the Adafruit Feather M0 LoRa, in dB
  .spi_freq = 8000000,
};


#define RFM_NSS     8
#define RFM_RST     4
#define RFM_IRQ     3
#define RFM_DIO01   9

void goToSleep() {
    digitalWrite(LED_WAN, LOW);
    digitalWrite(LED_SENSOR, LOW);
    digitalWrite(LED_BATT, LOW);
    
    digitalWrite(RS_485_EN, LOW);
    digitalWrite(I2C_EN, HIGH);

    digitalWrite(RE, HIGH);
    digitalWrite(DE, LOW);

    rtc.begin();
    rtc.setEpoch(0);
    rtc.enableAlarm(rtc.MATCH_YYMMDDHHMMSS);
    rtc.attachInterrupt(alarmMatch);

    rtc.setAlarmEpoch(rtc.getEpoch() + TX_INTERVAL);
    SysTick->CTRL &= ~SysTick_CTRL_TICKINT_Msk;
    rtc.standbyMode();
    SysTick->CTRL |= SysTick_CTRL_TICKINT_Msk;
}

void onEvent (ev_t ev) {
    Serial.print(os_getTime());
    Serial.print(": ");
    switch(ev) {
        case EV_SCAN_TIMEOUT:
            Serial.println(F("EV_SCAN_TIMEOUT"));
            break;
        case EV_BEACON_FOUND:
            Serial.println(F("EV_BEACON_FOUND"));
            break;
        case EV_BEACON_MISSED:
            Serial.println(F("EV_BEACON_MISSED"));
            break;
        case EV_BEACON_TRACKED:
            Serial.println(F("EV_BEACON_TRACKED"));
            break;
        case EV_JOINING:
            Serial.println(F("EV_JOINING"));
            // TTN uses SF9 for its RX2 window.
            LMIC.dn2Dr = EU868_DR_SF9;
            break;
        case EV_JOIN_TXCOMPLETE:
            Serial.println(F("EV_JOIN_TXCOMPLETE"));
            break;
        case EV_JOINED:
            Serial.println(F("EV_JOINED"));
            {
              u4_t netid = 0;
              devaddr_t devaddr = 0;
              u1_t nwkKey[16];
              u1_t artKey[16];
              LMIC_getSessionKeys(&netid, &devaddr, nwkKey, artKey);
              Serial.print("netid: ");
              Serial.println(netid, DEC);
              Serial.print("devaddr: ");
              Serial.println(devaddr, HEX);
              Serial.print("artKey: ");
              for (int i=0; i<sizeof(artKey); ++i) {
                if (i != 0)
                  Serial.print("-");
                Serial.print(artKey[i], HEX);
              }
              Serial.println("");
              Serial.print("nwkKey: ");
              for (int i=0; i<sizeof(nwkKey); ++i) {
                      if (i != 0)
                              Serial.print("-");
                      Serial.print(nwkKey[i], HEX);
              }
              Serial.println("");
            }
            // Disable link check validation (automatically enabled
            // during join, but because slow data rates change max TX
      // size, we don't use it in this example.
            LMIC_setLinkCheckMode(0);
            break;
        case EV_RFU1:
             Serial.println(F("EV_RFU1"));
             break;
        case EV_JOIN_FAILED:
            Serial.println(F("EV_JOIN_FAILED"));
            break;
        case EV_REJOIN_FAILED:
            Serial.println(F("EV_REJOIN_FAILED"));
            break;
            break;
        case EV_TXCOMPLETE:            
            Serial.println(F("EV_TXCOMPLETE (includes waiting for RX windows)"));
            digitalWrite(LED_WAN, LOW);
            
            if (LMIC.txrxFlags & TXRX_ACK)
              Serial.println(F("Received ack"));
            if (LMIC.dataLen) {
              Serial.println(F("Received "));
              Serial.println(LMIC.dataLen);
              Serial.println(F(" bytes of payload"));
            }
          
            goToSleep();
                              
            //os_setTimedCallback(&sendjob, os_getTime()+sec2osticks(TX_INTERVAL), do_send);
            do_send(&sendjob);
            break;
        case EV_LOST_TSYNC:
            Serial.println(F("EV_LOST_TSYNC"));
            break;
        case EV_RESET:
            Serial.println(F("EV_RESET"));
            break;
        case EV_RXCOMPLETE:
            // data received in ping slot
            Serial.println(F("EV_RXCOMPLETE"));
            break;
        case EV_LINK_DEAD:
            Serial.println(F("EV_LINK_DEAD"));
            break;
        case EV_LINK_ALIVE:
            Serial.println(F("EV_LINK_ALIVE"));
            break;
        case EV_SCAN_FOUND:
            Serial.println(F("EV_SCAN_FOUND"));
            break;
        
        case EV_TXSTART:
            Serial.println(F("EV_TXSTART"));
            digitalWrite(LED_WAN, HIGH);
            break;
        default:
            Serial.print(F("Unknown event: "));
            Serial.println((unsigned) ev);
            LMIC_reset();
            do_send(&sendjob);
            break;
    }
}

void do_send(osjob_t* j){
    // Check if there is not a current TX/RX job running
    if (LMIC.opmode & OP_TXRXPEND) {
        Serial.println(F("OP_TXRXPEND, not sending"));
    } else {
        LMIC_setTxData2(1, payload, 0, 0);
    }
    // Next TX is scheduled after TX_COMPLETE event.
}


void setup() {
    pinMode(DE, OUTPUT);//de
    pinMode(RE, OUTPUT);//~re
    digitalWrite(RE, HIGH);
    digitalWrite(DE, LOW);

    pinMode(LED_WAN, OUTPUT);
    pinMode(LED_SENSOR, OUTPUT);
    pinMode(LED_BATT, OUTPUT);
    
    pinMode(RS_485_EN, OUTPUT);
    digitalWrite(RS_485_EN, LOW);

    pinMode(I2C_EN, OUTPUT);
    digitalWrite(I2C_EN, HIGH);

    digitalWrite(LED_WAN, HIGH);
    digitalWrite(LED_SENSOR, HIGH);
    digitalWrite(LED_BATT, HIGH);
    delay(1000);
    digitalWrite(LED_WAN, LOW);
    digitalWrite(LED_SENSOR, LOW);
    digitalWrite(LED_BATT, LOW);
        
    Serial.begin(115200);
    Serial.println(F("Starting"));
    
    //TODO setup only for time of usage, costs ~1mA!
//    Serial5.begin(19200);
//    sensor.begin(1, Serial5);
//    sensor.preTransmission(preTransmission);
//    sensor.postTransmission(postTransmission);

    digitalWrite(LED_WAN, HIGH);
    os_init();
    LMIC_reset(); 
    LMIC_setLinkCheckMode(0);
    LMIC_setDrTxpow(EU868_DR_SF9, 14);

    delay(100);
    digitalWrite(LED_WAN, LOW);


    // Start job (sending automatically starts OTAA too)
//    do_send(&sendjob);
}

void loop() {
    delay(10000);
    goToSleep();
  //os_runloop_once();
  
}

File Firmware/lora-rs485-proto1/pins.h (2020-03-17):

#define DE          0
#define RE          1
#define LED_WAN     18
#define LED_SENSOR  17
#define LED_BATT    16
#define RS_485_EN   2
#define I2C_EN      5

#define RFM_NSS     8
#define RFM_RST     4
#define RFM_IRQ     3
#define RFM_DIO01   9

#define i2cEnable() digitalWrite(I2C_EN, LOW)
#define i2cDisable() digitalWrite(I2C_EN, HIGH)
#define rs485Enable() digitalWrite(RS_485_EN, HIGH)
#define rs485Disable() digitalWrite(RS_485_EN, LOW)
#define rs485Sleep() digitalWrite(RE, HIGH); digitalWrite(DE, LOW)
#define rs485DriverEnable()   digitalWrite(RE, HIGH); digitalWrite(DE, HIGH)
#define rs485ReaderEnable()   digitalWrite(DE, LOW); digitalWrite(RE, LOW)

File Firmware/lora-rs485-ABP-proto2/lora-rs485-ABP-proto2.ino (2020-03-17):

#include <SPI.h>
#include <ModbusMaster.h>
#include <RTCZero.h>

#include "pins.h"
#include "radio.h"

ModbusMaster sensor;

RTCZero rtc;

uint16_t batteryMillivolts = 0;

void alarmMatch() {
}

void preTransmission() {
  rs485DriverEnable();
}

void postTransmission() {
  rs485ReaderEnable();
}

// payload to send to TTN gateway
static uint8_t payload[5];

// Schedule TX every this many seconds (might become longer due to duty
// cycle limitations).
const unsigned TX_INTERVAL = 5;

void goToSleep() {
    digitalWrite(LED_WAN, LOW);
    digitalWrite(LED_SENSOR, LOW);
    digitalWrite(LED_BATT, LOW);
    
    digitalWrite(RS_485_EN, LOW);
    digitalWrite(I2C_EN, HIGH);

    digitalWrite(RE, HIGH);
    digitalWrite(DE, LOW);

    rtc.begin();
    rtc.setEpoch(0);
    rtc.enableAlarm(rtc.MATCH_YYMMDDHHMMSS);
    rtc.attachInterrupt(alarmMatch);

    rtc.setAlarmEpoch(rtc.getEpoch() + TX_INTERVAL);
    SysTick->CTRL &= ~SysTick_CTRL_TICKINT_Msk;
    rtc.standbyMode();
    SysTick->CTRL |= SysTick_CTRL_TICKINT_Msk;
}

int16_t temperature;
uint16_t moisture;


void readSensors() {
//  digitalWrite(LED_SENSOR, HIGH);
    rs485Enable();
    delay(30);

    Serial5.begin(19200);
    uint8_t result = sensor.readInputRegisters(0, 2);
    Serial5.end();
//    Serial.print("modbus result: "); Serial.println(result, HEX);
    
    moisture = sensor.getResponseBuffer(0);
    temperature = sensor.getResponseBuffer(1);
    batteryMillivolts = analogRead(A0) * 2 * 3300 / 1024;

//    Serial.print("Battery voltage: ");
//    Serial.println(batteryMillivolts);
//    Serial.print("Temperature: "); Serial.print(temperature);
//    Serial.println(" *C");
//    Serial.print("Moisture ");
//    Serial.println(moisture);

    rs485Disable();
    rs485Sleep();
//  digitalWrite(LED_SENSOR, LOW);
}

void setup() {
    pinMode(DE, OUTPUT);//de
    pinMode(RE, OUTPUT);//~re
    pinMode(LED_WAN, OUTPUT);
    pinMode(LED_SENSOR, OUTPUT);
    pinMode(LED_BATT, OUTPUT);
    pinMode(RS_485_EN, OUTPUT);
    pinMode(I2C_EN, OUTPUT);
    
    rs485Disable();    
    rs485Sleep();
    
    digitalWrite(LED_WAN, HIGH);
    digitalWrite(LED_SENSOR, HIGH);
    digitalWrite(LED_BATT, HIGH);
    delay(500);
    digitalWrite(LED_WAN, LOW);
    digitalWrite(LED_SENSOR, LOW);
    digitalWrite(LED_BATT, LOW);
        
    Serial.begin(9600);

    rtc.begin();
    rtc.setEpoch(0);
    rtc.enableAlarm(rtc.MATCH_YYMMDDHHMMSS);
    rtc.attachInterrupt(alarmMatch);
    
    sensor.begin(1, Serial5);
    sensor.preTransmission(preTransmission);
    sensor.postTransmission(postTransmission);

    Serial.println(F("Starting"));

    lora_init();
    readSensors();
    setupPayload();
    lora_send(payload, 6);
}

void on_tx_start() {
//  digitalWrite(LED_WAN, HIGH);
}

void on_tx_complete() {
//  digitalWrite(LED_WAN, LOW);
  goToSleep();        
  lora_adjust_time();  
  readSensors();
  setupPayload();  
  lora_send(payload, 6);
}

void setupPayload() {
        payload[0] = batteryMillivolts & 0x00FF;
        payload[1] = (batteryMillivolts >> 8) & 0x00FF;
        payload[2] = moisture & 0x00FF;
        payload[3] = (moisture >> 8) & 0x00FF;
        payload[4] = temperature & 0x00FF;
        payload[5] = (temperature >> 8) & 0x00FF;
}

void loop() {
  os_runloop_once();
}

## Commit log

2019-09-21 Add electronics designed so far
    [battery-protection.sch, i2c-interface.sch, lora-bridge.kicad_pcb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]
2019-09-21 Add price calculation for hardware
    [Price calculation.ods]
2019-09-21 Make more calculations
    [Price calculation.ods]
2019-09-21 Some PCB routing is done
    [1051330011.stp, battery-protection.sch, i2c-interface.sch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]
2019-11-04 Add ESD protection to i2c lines, change VIN TVS diode to higher voltage, add series resistors to SPI lines, compress the PCB to be at width of typical 4xAA battery holder
    [battery-protection.sch, current calculations.ods, i2c-interface.sch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]
2020-01-10 Add power input PTC fuse
    [battery-protection.sch, lora-bridge.kicad_pcb, lora-bridge.sch]
2020-01-10 Add some 3d models and colateral documentation
    [732511150.stp, c-2334884-1-a2-3d.stp]
2020-01-10 Add manufacturing files
    [lora-bridge-B_Cu.gbr, lora-bridge-B_Mask.gbr, lora-bridge-B_Paste.gbr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]
2020-01-10 Improve modbus comm debug message, add possible sleep hang fix to proto2 firmware
    [lora-rs485-ABP-proto2.ino, lora-rs485-proto2.ino]
2020-01-14 Add pullup to SWDCLK for better stability. Change reset pullup value to 1k
    [battery-protection.sch, i2c-interface.sch, lora-bridge.kicad_pcb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]
2020-01-17 Update D3 to silicone diode as schottky leaks as hell; Add D2 to protect gates of mosfets; Remove series resistors from RFM95 interface, add pullups/downs for better sleep stability; Unify resistor v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
    [SMA-J-P-H-ST-EM1.STP--3DModel-STEP-66336.STEP, battery-protection.sch, current calculations.ods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]
2020-01-17 Fix info on silkscreen, remove RF connector pads from paste layer
    [lora-bridge.kicad_pcb]
2020-01-24 Move R11 and accompanying components a bit so it's easier to replace it. Add fiducials. Generate gerbers for v1.2
    [battery-protection.sch, i2c-interface.sch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]
2020-02-21 Move around vias so power planes are not so much broken. Move connectors closer together so all of them are on 5.08mm grid
    [battery-protection.sch, i2c-interface.sch, lora-bridge.kicad_pcb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]
2020-02-21 Just a touch
    [lora-bridge.kicad_pcb]
2020-03-23 Tune up prototype1 FW for board testing, chase kicad format changes
    [lora-bridge-bom.csv, lora-bridge-v1.2.csv, lora-bridge.kicad_pcb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]
